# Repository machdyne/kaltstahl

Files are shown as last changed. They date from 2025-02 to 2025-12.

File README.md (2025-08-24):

# Kaltstahl Storage Device

Kaltstahl is a higher capacity version of [Blaustahl](https://github.com/machdyne/blaustahl).

## Firmware

Kaltstahl can use either the Blaustahl (USB-CDC) or [Ebenstahl](https://github.com/machdyne/ebenstahl) (USB-MSC) firmware.

The default firmware images are [available here](firmware).

Please see the [Blaustahl](https://github.com/machdyne/blaustahl) repo for instructions and firmware source code for the USB-CDC firmware.

To build the firmware from the source code, you will need to modify blaustahl.h and change the FRAM\_SIZE value to 262144 and then use the following commands:

```
$ mkdir build
$ cd build
$ cmake -DPICO_DEFAULT_BOOT_STAGE2_FILE=/your-pico-sdk-directory/pico-sdk/src/rp2040/boot_stage2/boot2_generic_03h.S ..
$ make
```

## License

The contents of this repo are released under the [Lone Dynamics Open License](LICENSE.md).

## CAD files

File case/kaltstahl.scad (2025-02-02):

/*
 * Kaltstahl Case
 * Copyright (c) 2024 Lone Dynamics Corporation. All rights reserved.
 *
 * required hardware:
 *  - 1 x M2.5 x 12mm countersunk bolt
 *  - 1 x M2.5 nut
 *
 */
 
$fn = 30;

box_width = 19;
box_length = 37;
box_height = 12.5;
box_thickness = 2.0;

lid_thickness = 3;

cutout_width = 16.10;
cutout_length = 44;
cutout_height = 6.5;

cutout_usb_width = 12.2;

board_height = 1.4;

roundness = 1;

toladj = 0.25;

ldp_board(-1.75);
translate([0,0,-0.5]) ldp_case();
ldp_endcap(0);

// m2.5 bolt
//translate([0,-13.5,-6.25]) color([1,0,0]) cylinder(d=2.5, h=12, $fn=36);

// m2.5 nut
//translate([0,-13.5,-6.55]) rotate(30) color([1,0,0]) cylinder(d=5.8, h=2.4, $fn=6);

module ldp_endcap(o)
{
		 	
	difference() {
		union() {
			translate([0,-13.5,o-0.775]) color([0,0,1]) cylinder(d=6, h=4, $fn=36);
			translate([0,-13.5,o-3.225]) color([0,0,1]) cylinder(d=4, h=3.5, $fn=36);
			translate([0,-13.5,o-3.225]) color([0,0,1]) cylinder(d=8, h=1, $fn=36);
			translate([0,-16,0]) cube([16,5,6.45], center=true);
		}
		translate([0,-13.5,-4.25]) color([1,0,0]) cylinder(d=3, h=8, $fn=36);
		
      	translate([0,-18,-1]) rotate([90,0,0])
		linear_extrude(1)
			text("KALTSTAHL", size=2, halign="center", font="Lato Black");


	}
}

module ldp_board(o)
{
	
	difference() {
		union() {
			translate([0,2,o])
				color([0.0,0.8,0.0]) cube([16, 30, 1.6], center=true);
			translate([0,23,o+1.45])
				color([0.9,0.9,0.9]) cube([12, 15, 4.5], center=true);
		}
		translate([0,-13,-10]) cylinder(d=4.2, h=100);
	}
	
}

module ldp_case()
{
	
	difference() {
		
		minkowski() {
			cube([box_width-(roundness*2),box_length-(roundness*2),box_height-(roundness*2)],
				center=true);
			sphere(roundness);
		}
	
		translate([0,-5,(box_height-cutout_height)/2-2.5])
			cube([cutout_width+toladj,cutout_length,cutout_height], center=true);

		// USB cutout
		translate([0,15,0.25])
			cube([cutout_usb_width+toladj,10,4.6+toladj], center=true);

		// bolt hole
		translate([0,-13.5,-5]) cylinder(d=2.75+toladj, h=100, $fn=36);
		
		// nut cutout
		translate([0,-13.5,-6.75]) rotate(30) cylinder(d=6+toladj, h=2.5, $fn=6);
		
		// lid notch cutout
		translate([0,-13.5,5.25]) cylinder(d=5+toladj, h=100);

	}

}

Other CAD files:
case/kaltstahl_neu.scad

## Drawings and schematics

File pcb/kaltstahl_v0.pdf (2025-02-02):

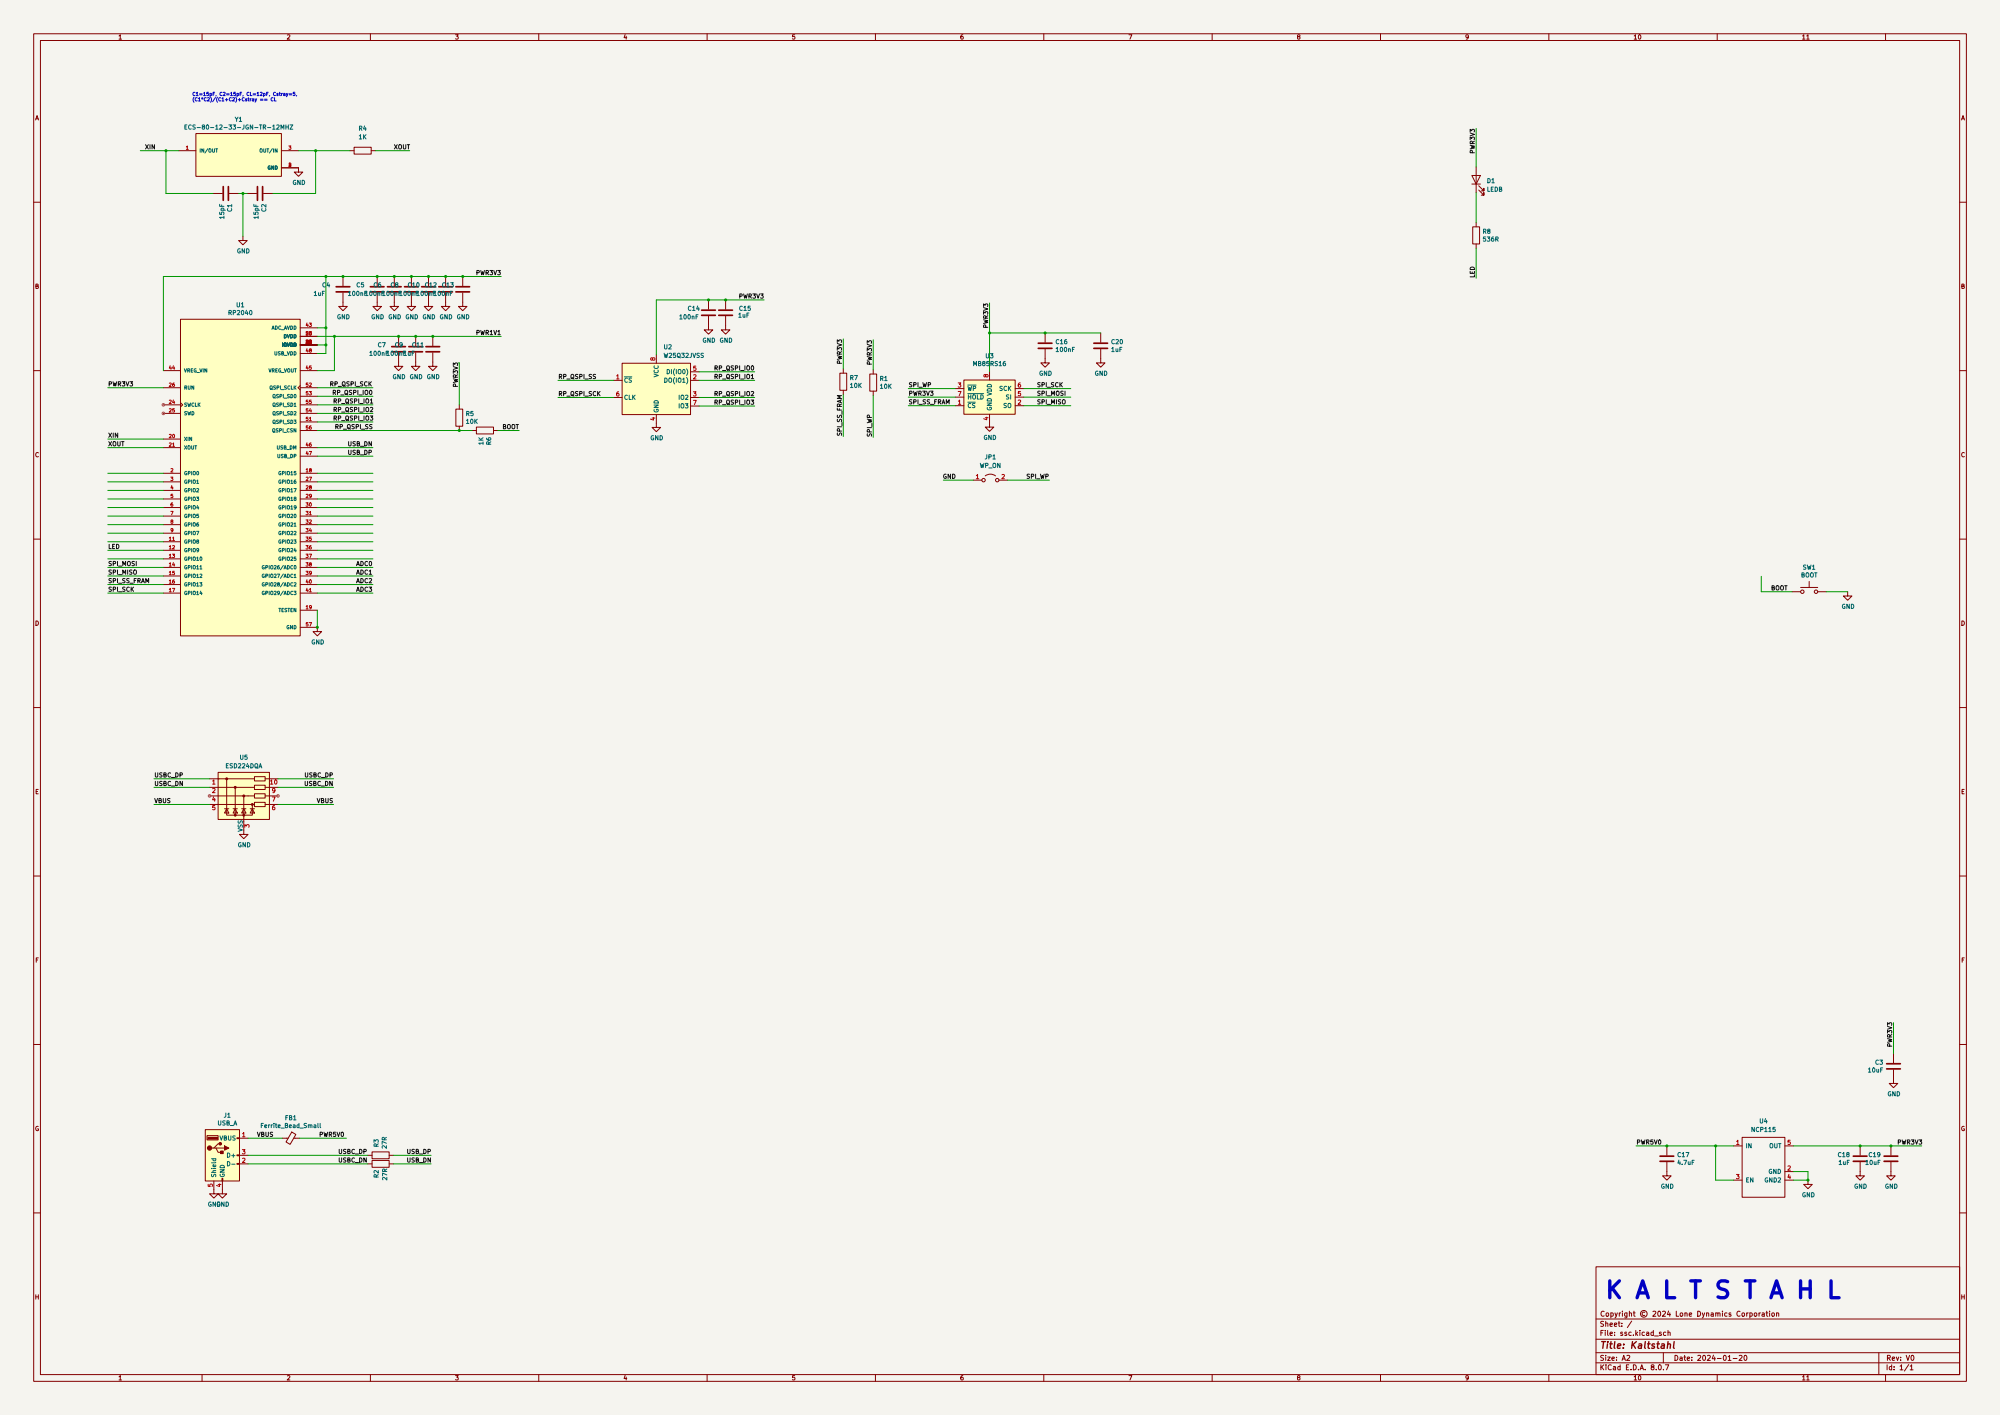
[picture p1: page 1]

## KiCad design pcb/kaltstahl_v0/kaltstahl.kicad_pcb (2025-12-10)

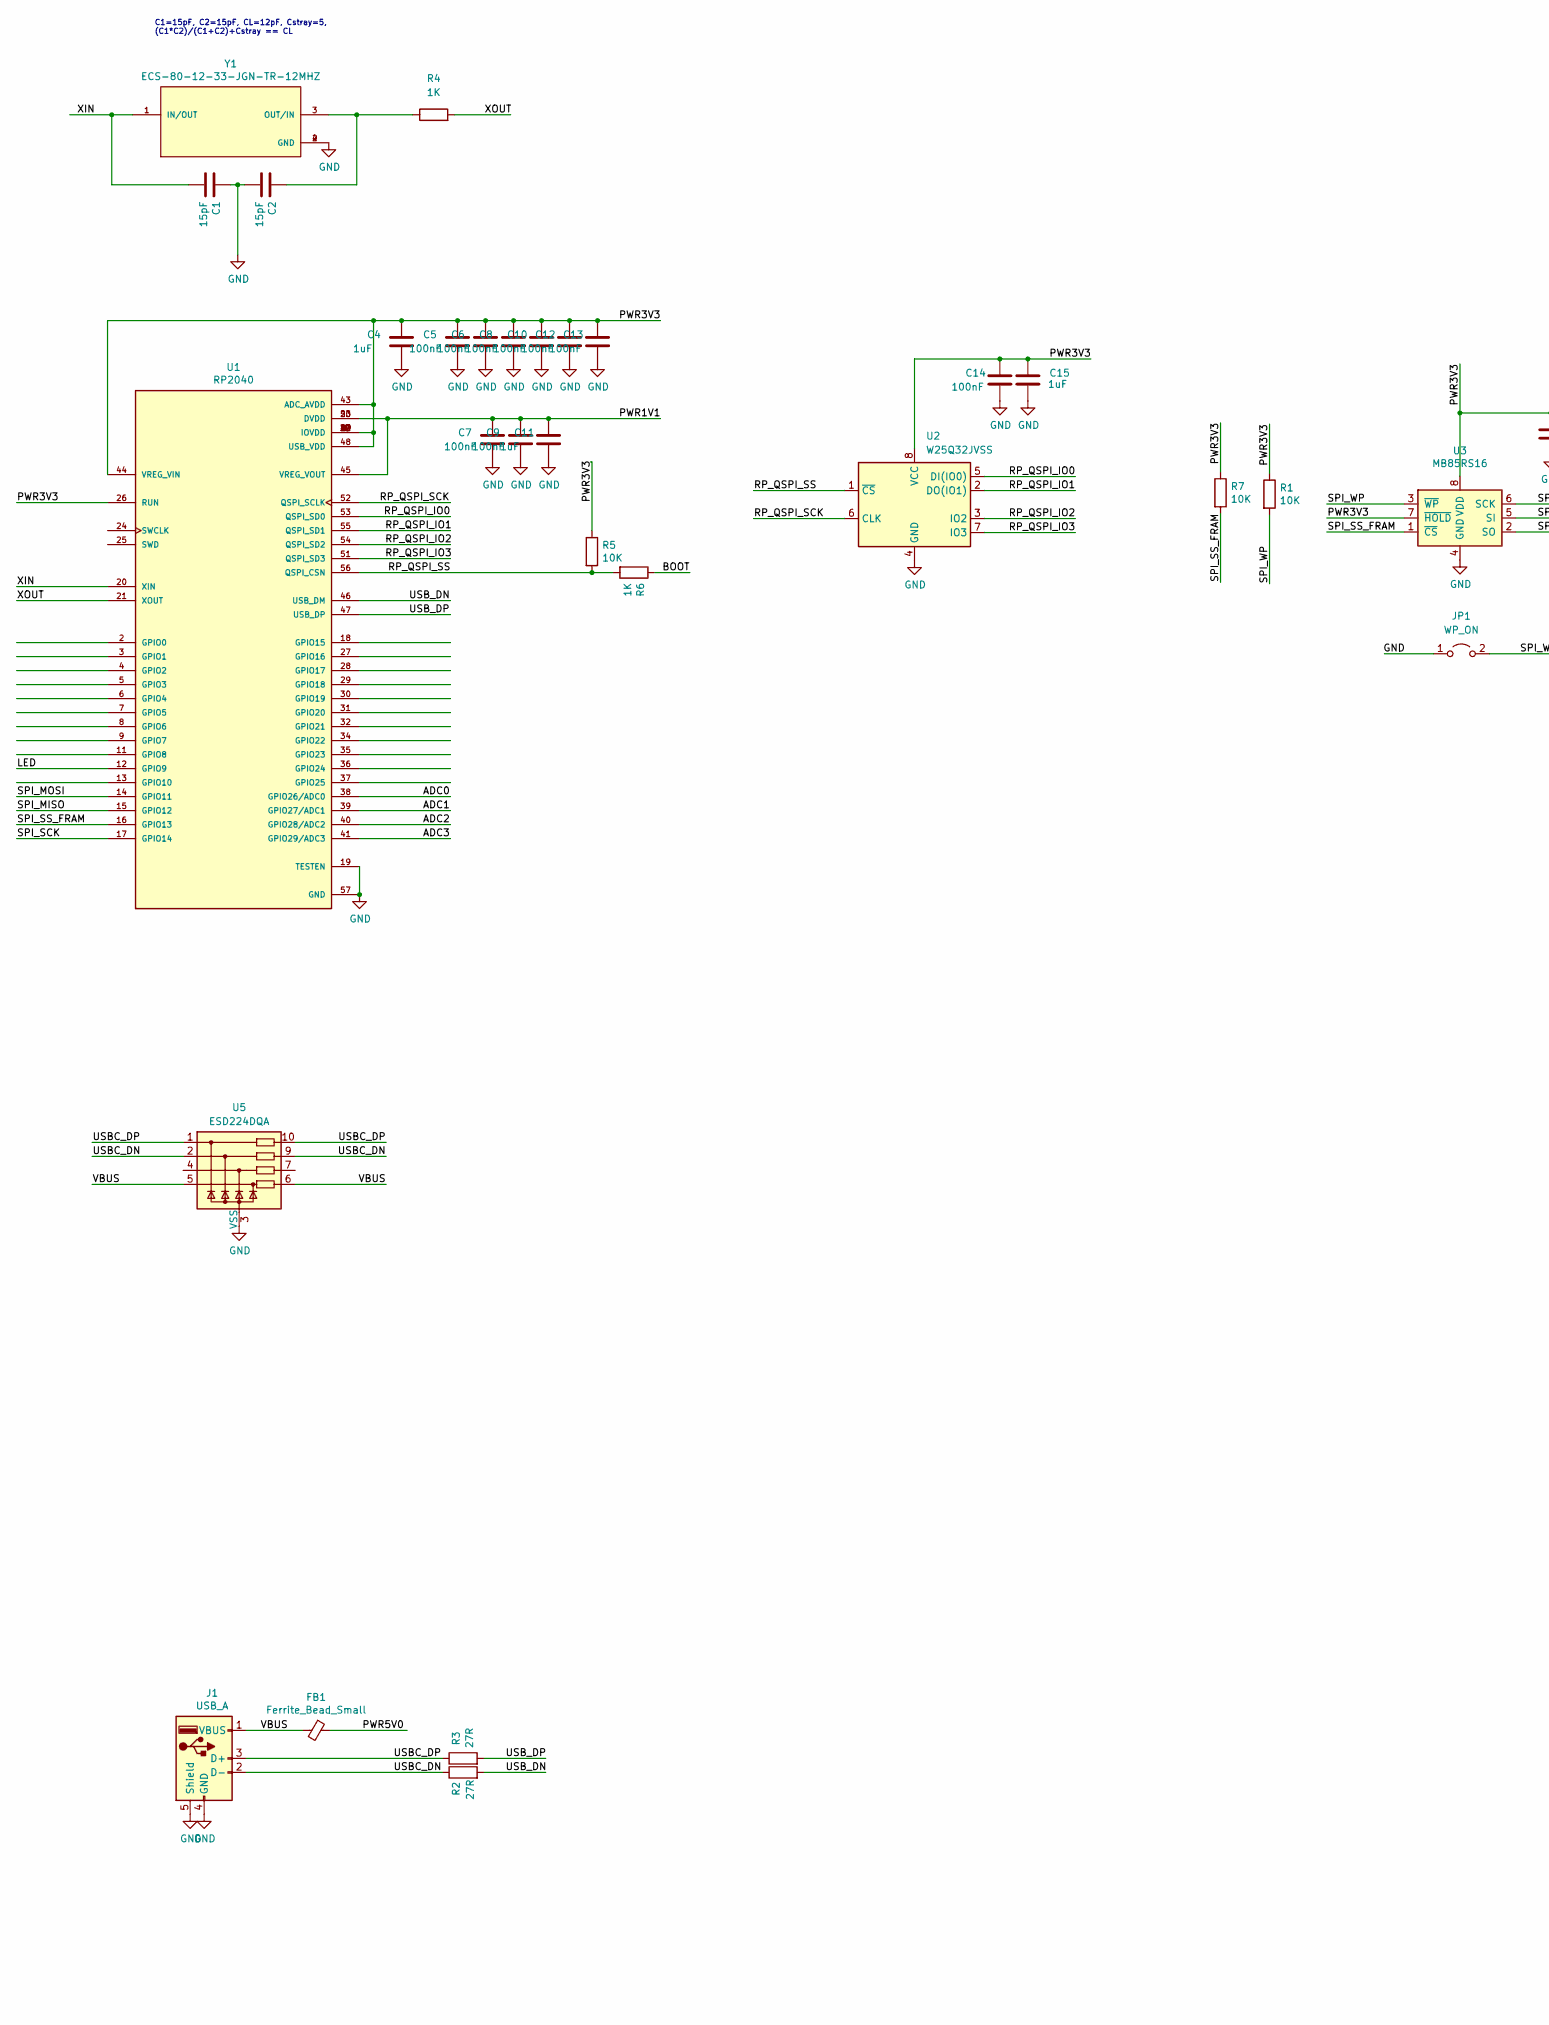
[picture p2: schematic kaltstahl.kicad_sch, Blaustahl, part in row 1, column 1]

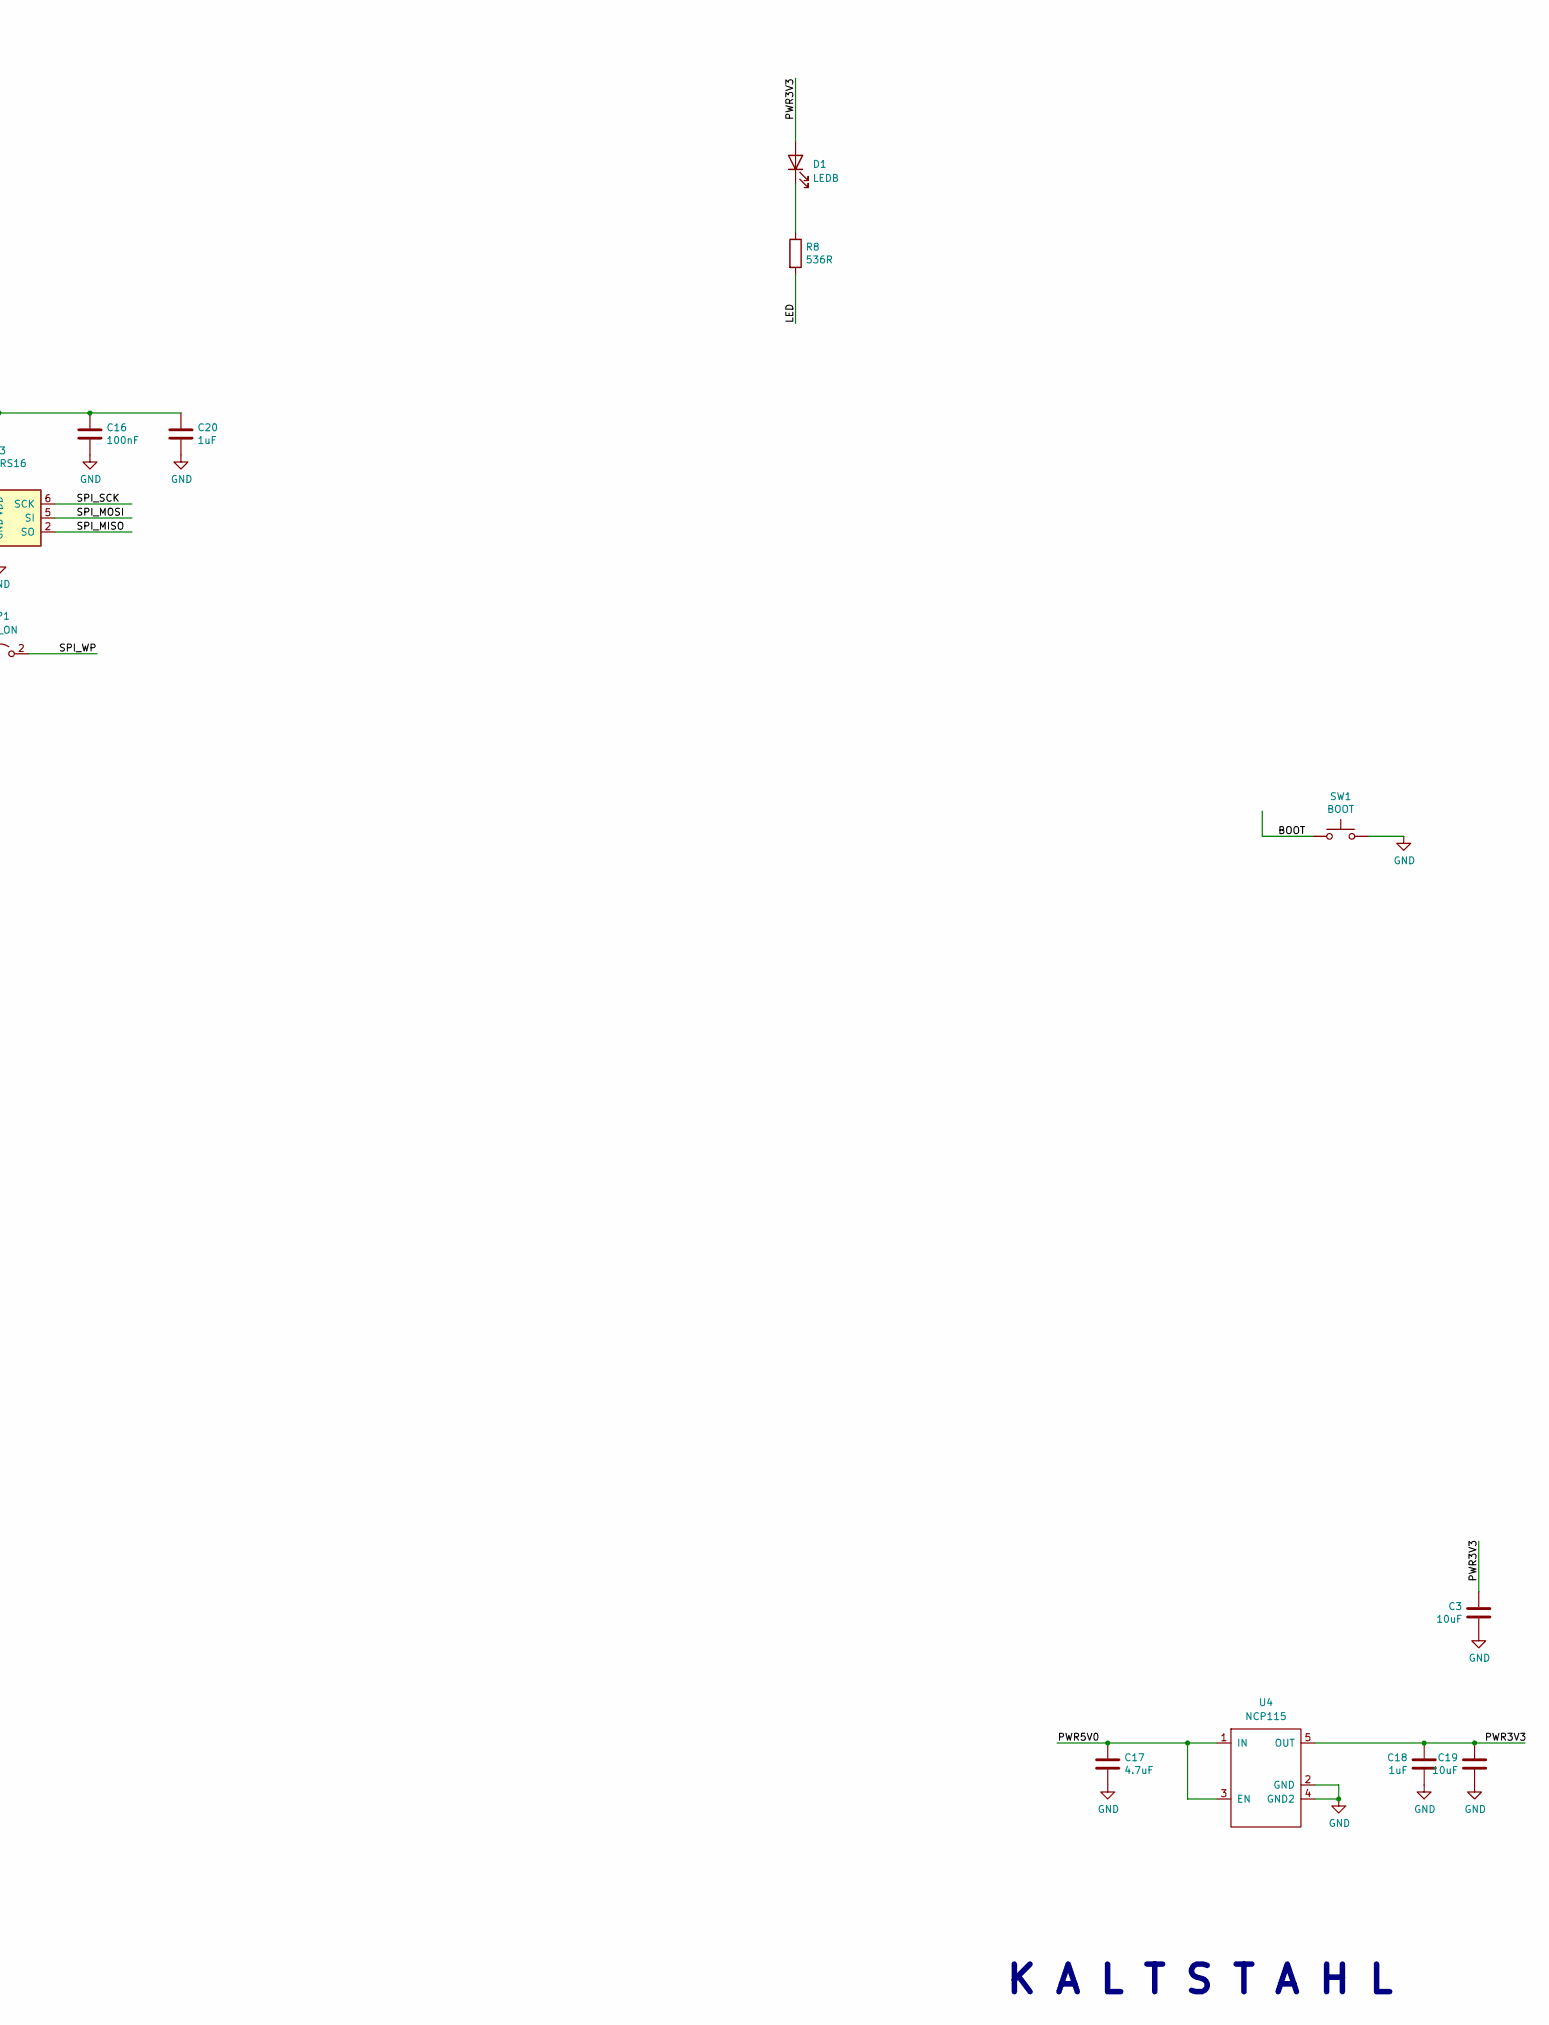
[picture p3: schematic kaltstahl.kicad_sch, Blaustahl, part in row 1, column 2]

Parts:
C1, C2: 15pF; C_0402_1005Metric
C3, C19: 10uF; C_0402_1005Metric
C4, C11, C15, C18, C20: 1uF; C_0402_1005Metric
C5, C6, C7, C8, C9, C10, C12, C13, C14, C16: 100nF; C_0402_1005Metric
C17: 4.7uF; C_0402_1005Metric
D1: LEDB; LED_0603_1608Metric
FB1: Ferrite_Bead_Small; R_0402_1005Metric
J1: USB_A; USB_A_CNCTech_1001-011-01101_Horizontal
JP1: WP_ON; SolderJumper-2_P1.3mm_Open_Pad1.0x1.5mm
R1, R5, R7: 10K; R_0402_1005Metric
R2, R3: 27R; R_0402_1005Metric
R4, R6: 1K; R_0402_1005Metric
R8: 536R; R_0402_1005Metric
SW1: BOOT; Button_2P_3x4mm
U1: RP2040; RP2040-QFN-56-OFFICIAL; PARTREV 1.6.1
U2: W25Q32JVSS; SOIC-8_3.9x4.9mm_P1.27mm
U3: MB85RS16; SOIC-8_3.9x4.9mm_P1.27mm
U4: NCP115; TSOP-5_1.65x3.05mm_P0.95mm
U5: ESD224DQA; Diodes_UDFN-10_1.0x2.5mm_P0.5mm
Y1: ECS-80-12-33-JGN-TR-12MHZ; XTAL_ECS-240-8-33-AGN-TR

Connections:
/ADC0: U1.38 (GPIO26/ADC0)
/ADC1: U1.39 (GPIO27/ADC1)
/ADC2: U1.40 (GPIO28/ADC2)
/ADC3: U1.41 (GPIO29/ADC3)
/BOOT: R6.1, SW1.1
/LED: R8.2, U1.12 (GPIO9)
/PWR1V1: C7.1, C9.1, C11.1, U1.23 (DVDD), U1.45 (VREG_VOUT), U1.50 (DVDD)
/PWR3V3: C3.1, C4.1, C5.1, C6.1, C8.1, C10.1, C12.1, C13.1, C14.1, C15.1, C16.1, C18.1, C19.1, C20.1, D1.2 (A), R1.1, R5.1, R7.1, U1.1 (IOVDD), U1.10 (IOVDD), U1.22 (IOVDD), U1.26 (RUN), U1.33 (IOVDD), U1.42 (IOVDD), U1.43 (ADC_AVDD), U1.44 (VREG_VIN), U1.48 (USB_VDD), U1.49 (IOVDD), U2.8 (VCC), U3.7 (~HOLD), U3.8 (VDD), U4.5 (OUT)
/PWR5V0: C17.1, FB1.1, U4.1 (IN), U4.3 (EN)
/RP_QSPI_IO0: U1.53 (QSPI_SD0), U2.5 (DI(IO0))
/RP_QSPI_IO1: U1.55 (QSPI_SD1), U2.2 (DO(IO1))
/RP_QSPI_IO2: U1.54 (QSPI_SD2), U2.3 (IO2)
/RP_QSPI_IO3: U1.51 (QSPI_SD3), U2.7 (IO3)
/RP_QSPI_SCK: U1.52 (QSPI_SCLK), U2.6 (CLK)
/RP_QSPI_SS: R5.2, R6.2, U1.56 (QSPI_CSN), U2.1 (~CS)
/SPI_MISO: U1.15 (GPIO12), U3.2 (SO)
/SPI_MOSI: U1.14 (GPIO11), U3.5 (SI)
/SPI_SCK: U1.17 (GPIO14), U3.6 (SCK)
/SPI_SS_FRAM: R7.2, U1.16 (GPIO13), U3.1 (~CS)
/SPI_WP: JP1.2 (B), R1.2, U3.3 (~WP)
/USBC_DN: J1.2 (D-), R2.1, U5.2, U5.9
/USBC_DP: J1.3 (D+), R3.1, U5.1, U5.10
/USB_DN: R2.2, U1.46 (USB_DM)
/USB_DP: R3.2, U1.47 (USB_DP)
/VBUS: FB1.2, J1.1 (VBUS), U5.5, U5.6
/XIN: C1.2, U1.20 (XIN), Y1.1 (IN/OUT)
/XOUT: R4.2, U1.21 (XOUT)
GND: C1.1, C2.2, C3.2, C4.2, C5.2, C6.2, C7.2, C8.2, C9.2, C10.2, C11.2, C12.2, C13.2, C14.2, C15.2, C16.2, C17.2, C18.2, C19.2, C20.2, J1.4 (GND), J1.5 (Shield), JP1.1 (A), SW1.2, U1.19 (TESTEN), U1.57 (GND), U2.4 (GND), U3.4 (GND), U4.2 (GND), U4.4 (GND2), U5.3 (VSS), U5.8 (VSS), Y1.2 (GND), Y1.4 (GND)
unnamed: D1.1 (K), R8.1
unnamed: C2.1, R4.1, Y1.3 (OUT/IN)

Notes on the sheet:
C1=15pF, C2=15pF, CL=12pF, Cstray=5, (C1*C2)/(C1+C2)+Cstray == CL
K A L T S T A H L

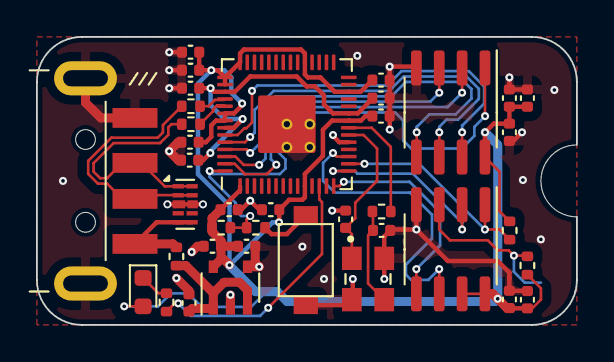
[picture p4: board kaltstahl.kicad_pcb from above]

Board: 2 copper layers, 30.0 x 16.0 mm, 39 parts (1 on the bottom side), 26 nets.

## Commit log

2025-02-02 add v0 schematics
2025-12-10 add pcb
    [kaltstahl.kicad_pcb, kaltstahl.kicad_sch]
2026-06-19 add new case design
    [kaltstahl_neu.scad]

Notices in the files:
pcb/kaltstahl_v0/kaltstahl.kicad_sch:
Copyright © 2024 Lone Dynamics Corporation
